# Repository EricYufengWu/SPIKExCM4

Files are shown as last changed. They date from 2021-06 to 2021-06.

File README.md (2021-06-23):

## Raspberry Pi CM4 Carrier Board for LEGO SPIKE Prime

This is the final project for my Microcontrollers Programming Class. My professor gave us an open prompt which is "create something that is useful". With my previous experience and interests in designing LEGO Robotics expansion hardware, I developed a Raspberry Pi CM4 Carrier board specifically for the LEGO SPIKE Prime educational system. In short, this is a slim, self-contained add-on to the SPIKE Prime hub. It gives the educational platform a huge boost in computational power and peripheral connectivity, making it capable of running tasks such as image processing, machine learning, ROS, and more.

**Note: As of June 23rd, 2021, the camera ports unfortunately do not work on the current version (In short, I made a dumb mistake of using a different footprint for the camera connectors, which has all the pins backwards). Connecting a camera may result in the flex cable heating up or possibly some permanent damage to the CM4 board. If I ever got the chance to make another design iteration, this will be the first thing I will tackle. :(**

Youtube: https://youtu.be/AbPgGo25kjA

GrabCAD: https://grabcad.com/library/raspberry-pi-cm4-carrier-board-for-lego-spike-prime-1

For more information about this project, please checkout https://www.yufengwu.com/work/class-projects/cm4-carrier-board

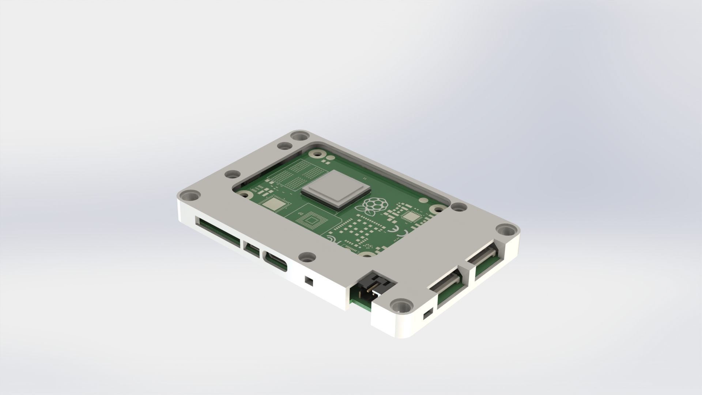
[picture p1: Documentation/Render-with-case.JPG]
Rendering

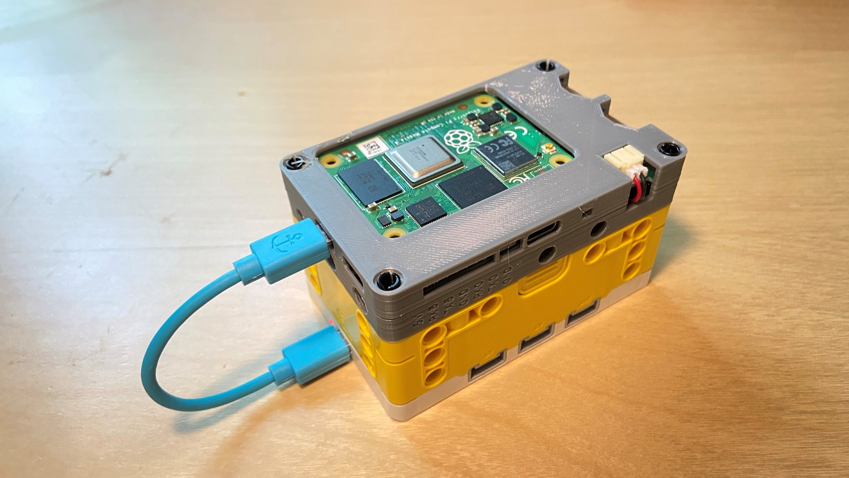
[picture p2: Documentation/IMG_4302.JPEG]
Finished


## Hardware Components
To make this backpack yourself, you'll need the following hardware components:
* The carrier board PCB itself. I got the full assembly service from PCBWay, but you are welcome to find your own PCB manufacturer.
* A [Raspberry Pi Compute Module 4](https://www.raspberrypi.org/products/compute-module-4/?variant=raspberry-pi-cm4001000) **with onboard EMMC and WiFi module**. 
* Some right-angle pin headers. [Amazon Link](https://www.amazon.com/Uxcell-a14032500ux0426-Right-Header-Spacing/dp/B010ESD338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)
* A 3.7V Lithium Polymer (LiPoly) battery with JST-PH connector in the correct polarity. It has to be both slim enough to fit inside the housing and powerful enough to handle around 1.5A nominal and 3A burst current. [Digikey Link](https://www.digikey.com/en/products/detail/jauch-quartz/LP605060JU-PCM-WIRES-70MM/9560993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)
* A short microB male to microB male USB cable. [Digikey Link](https://www.digikey.com/en/products/detail/CAB0701/1778-1018-ND/6928231?itemSeq=364421679)
* A standard hobbyist 3D printer with PLA filament (Prusa MK3S, Prusa MINI, Ender3, etc.).

## Getting Started with the Carrier Board
1. Install the compute module onto the carrier board. Make sure to get one with EMMC memory (you probably want one with WiFi as well)
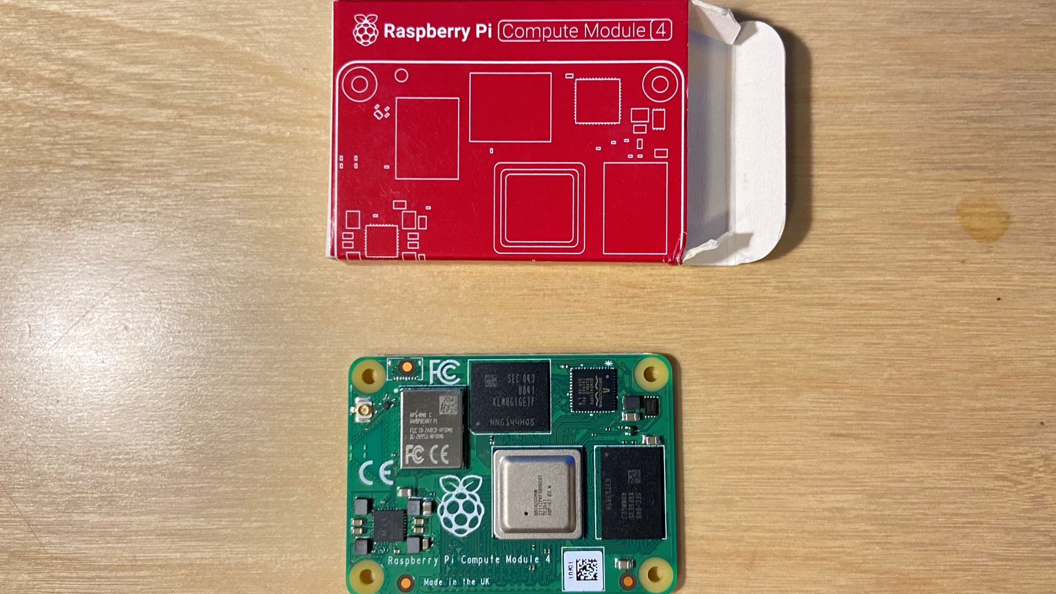
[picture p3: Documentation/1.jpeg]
CM4


1. Close the jumper (see pic) to disable EMMC boot. 
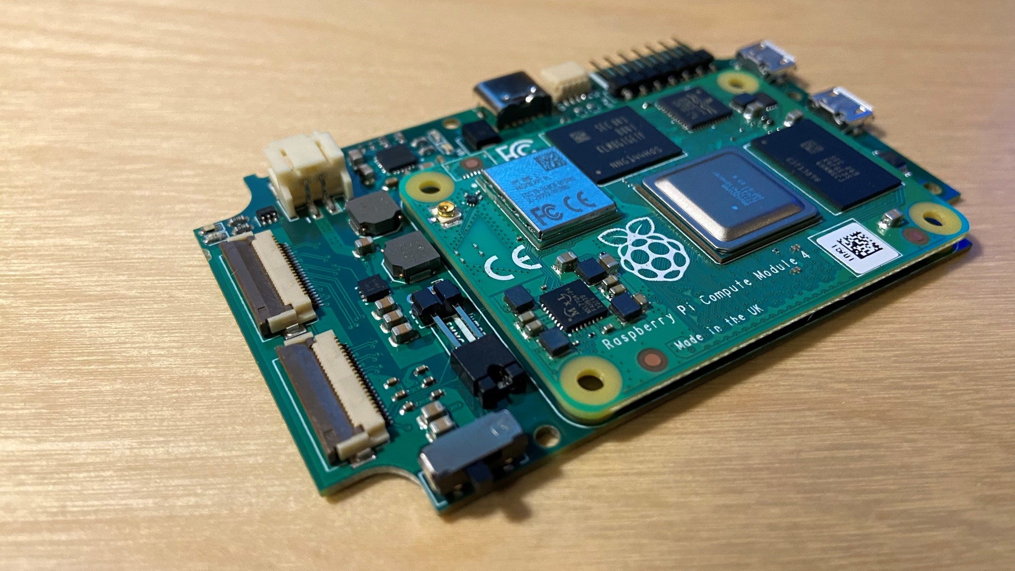
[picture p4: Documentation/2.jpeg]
Jumper Open

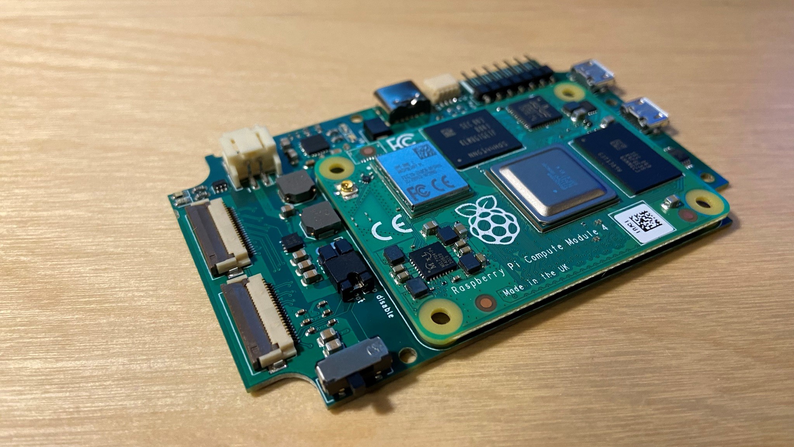
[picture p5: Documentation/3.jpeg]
Jumper Closed


1. Connect a microUSB data cable from the OTG port (the one closer to the corner) to your laptop.
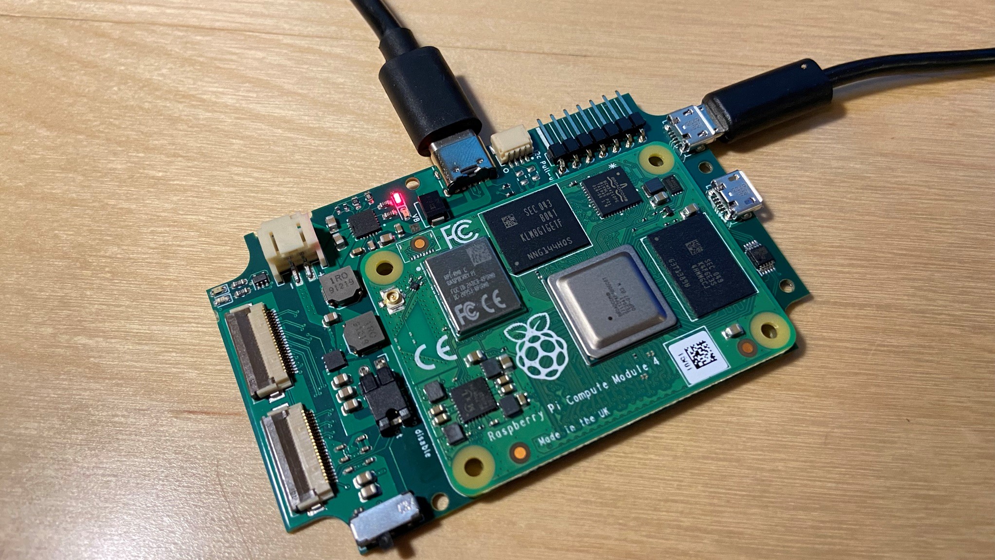
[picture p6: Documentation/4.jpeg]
OTG


1. Follow [this link](https://www.raspberrypi.org/documentation/hardware/computemodule/cm-emmc-flashing.md) to flash the compute module's EMMC. The spscific steps depend on your computer's operating system (see the link for details). After this, you should have an operating system of your choice installed on the compute module. 

1. To minimize its size, this board is designed to have your Pi communicate with your computer via a serial console cable. You may now follow [this link](https://learn.adafruit.com/adafruits-raspberry-pi-lesson-5-using-a-console-cable/overview) to set up the communication. As for the "Connecting the Lead" section, refer to the following picture for wiring. Specifically, you'll want the following line of text be added to the last line of config.txt, which you may found in your Pi as a mass storage device right after writing the OS onto your compute module.
    ```
    enable_uart=1
    ```
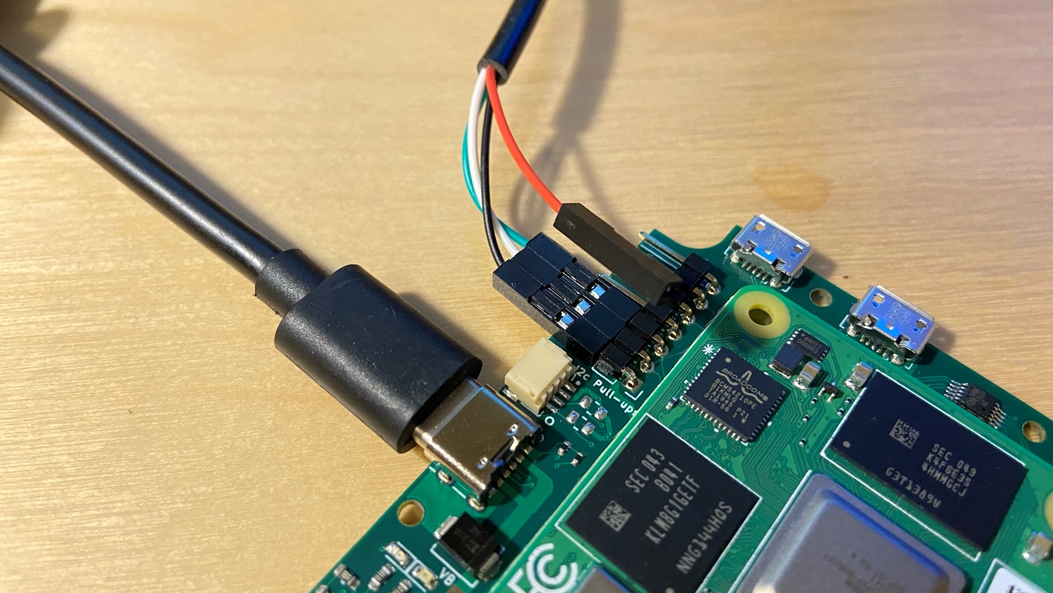
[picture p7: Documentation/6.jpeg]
Serial Console


1. For thir carrier board specifically, you also might want to add the following to config.txt, since the GPIO pins for UART5 were also made available in case you want to use the console cable and UART at the same time.
    ```
    dtoverlay=uart5
    ```

1. If the TTL cable connection is successful, you may continue to set up other hardware, such as WiFi and USB, in order to release the full potential of your compute module. You may use a short microB male to microB male USB cable to connect your carriar board to a LEGO SPIKE Prime. To enable USB, add the following line to config.txt:
    ```
    dtoverlay=dwc2,dr_mode=host
    ```

1. Happy hacking!

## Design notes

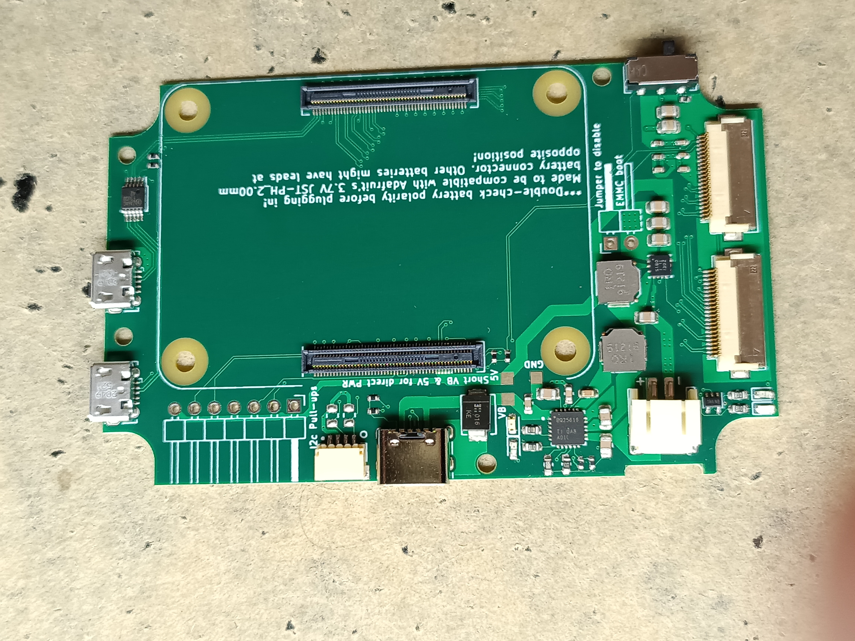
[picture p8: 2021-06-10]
Documentation/Finished_front.jpg

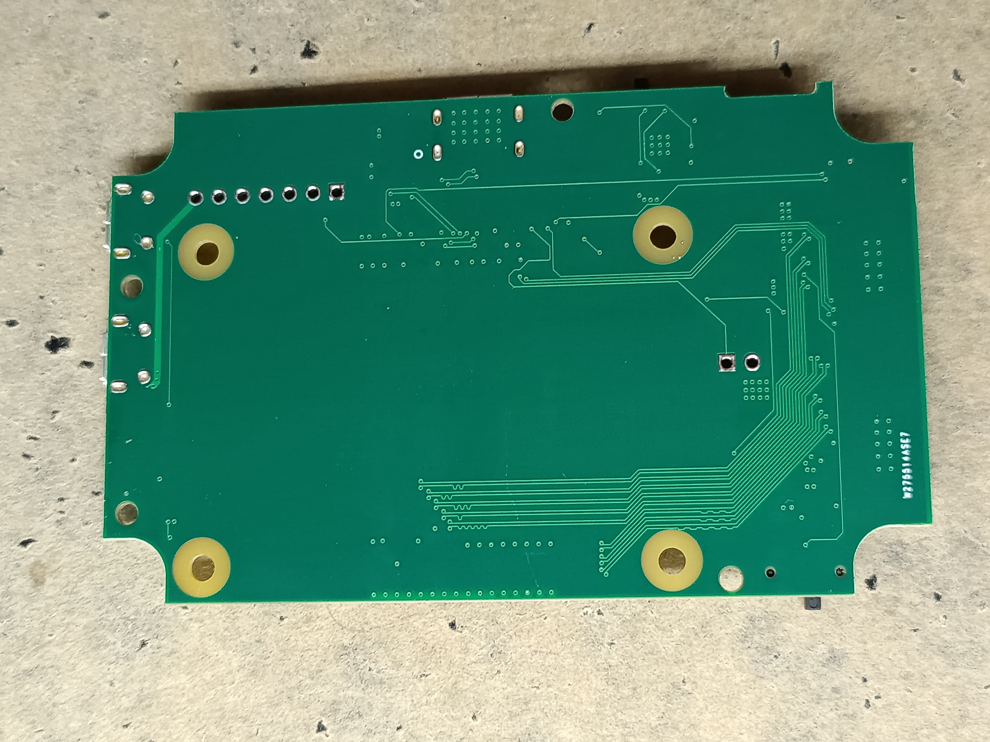
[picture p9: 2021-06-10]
Documentation/Finished_back.jpg

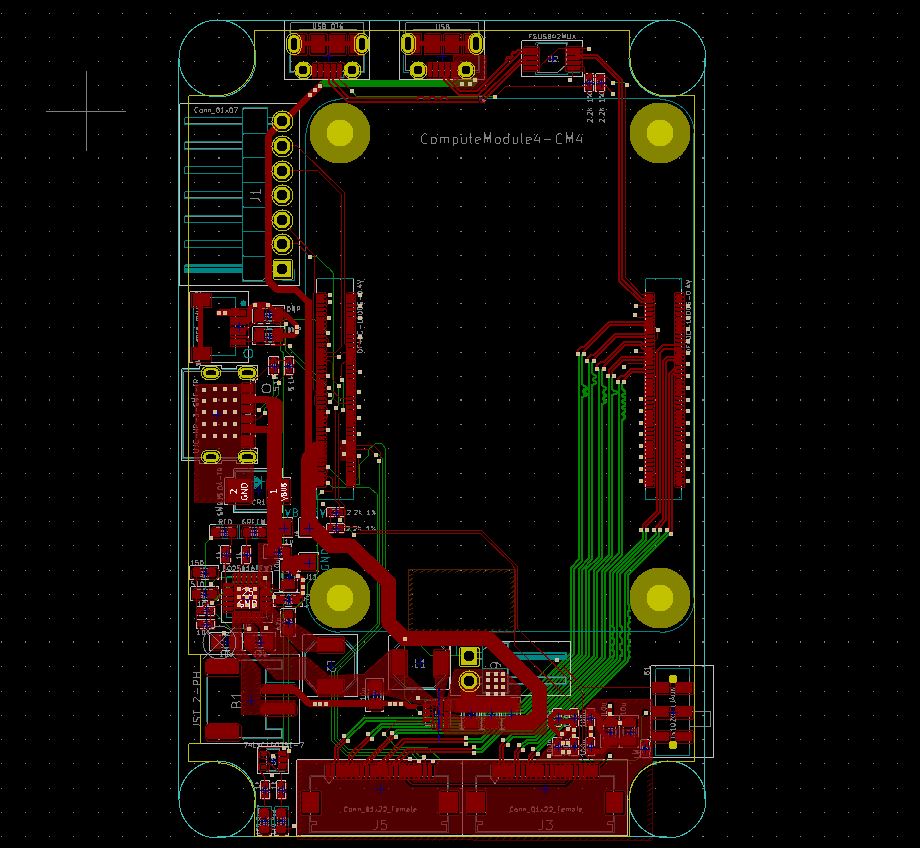
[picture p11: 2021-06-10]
Documentation/layout.JPG

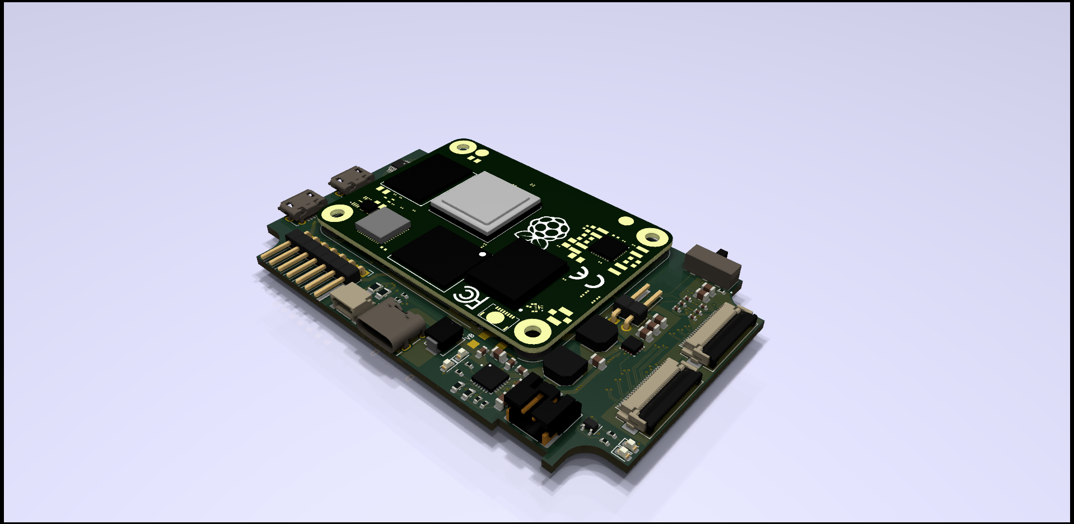
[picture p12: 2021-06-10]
Documentation/rpi-cm4-carrier-v0-render.png

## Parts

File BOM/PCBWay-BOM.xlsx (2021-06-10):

 |  |  | xxxx xxxx xxxxx xxPCS BOM (Sample Bill of Materials)
Item # | *Designator | *Qty | Manufacturer | *Mfg Part # | Description / Value | *Package/Footprint | Type | Your Instructions / Notes
1 | B1 | 1 | JST Sales America Inc. | S2B-PH-SM4-TB(LF)(SN) | Connector Header Surface Mount, Right Angle 2 position 0.079" (2.00mm) | 2.00mm pitch | SMD | https://www.digikey.com/en/products/detail/jst-sales-america-inc/S2B-PH-SM4-TB-LF-SN/926655
2 | C1,C2,C9,C10,C12,C13,C14,C17,C18 | 9 | Samsung Electro-Mechanics | CL21A106KPFNNWE | 10uF ±10% 10V Ceramic Capacitor X5R 0805 (2012 Metric) | 0805 | SMD | https://www.digikey.com/en/products/detail/samsung-electro-mechanics/CL21A106KPFNNWE/3888555
3 | C3,C4,C5,C6,C7,C8 | 6 | Samsung Electro-Mechanics | CL05B104KP5NNNC | 0.1uF ±10% 10V Ceramic Capacitor X7R 0402 (1005 Metric) | 0402 | SMD | https://www.digikey.com/en/products/detail/samsung-electro-mechanics/CL05B104KP5NNNC/3886660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
4 | C11 | 1 | Samsung Electro-Mechanics | CL10B105KP8NNNC | 1uF ±10% 10V Ceramic Capacitor X7R 0603 (1608 Metric) | 0603 | SMD | https://www.digikey.com/en/products/detail/samsung-electro-mechanics/CL10B105KP8NNNC/3887604
5 | C15 | 1 | Vishay Vitramon | VJ0603Y473JXQPW1BC | 0.047uF ±5% 10V Ceramic Capacitor X7R 0603 (1608 Metric) | 0603 | SMD | https://www.digikey.com/en/products/detail/vishay-vitramon/VJ0603Y473JXQPW1BC/8306338
6 | C16 | 1 | Samsung Electro-Mechanics | CL10A475KP8NNNC | 4.7uF ±10% 10V Ceramic Capacitor X5R 0603 (1608 Metric) | 0603 | SMD | https://www.digikey.com/en/products/detail/samsung-electro-mechanics/CL10A475KP8NNNC/3886702
7 | CR1 | 1 | Diodes Incorporated | SMBJ5.0A-13-F | TVS DIODE 5V 9.2V SMB | DO-214AA, SMB | SMD | https://www.digikey.com/en/products/detail/diodes-incorporated/SMBJ5-0A-13-F/725039
8 | D1,D3 | 2 | OSRAM Opto Semiconductors Inc. | LG Q396-PS-35 | Green 573nm LED Indication - Discrete 2V 0603 (1608 Metric) | 0603 | SMD | https://www.digikey.com/en/products/detail/osram-opto-semiconductors-inc/LG-Q396-PS-35/5249855
9 | D2,D4 | 2 | OSRAM Opto Semiconductors Inc. | LED RED DIFFUSED 0603 SMD | Red 630nm LED Indication - Discrete 1.8V 0603 (1608 Metric) | 0603 | SMD | https://www.digikey.com/en/products/detail/osram-opto-semiconductors-inc/LS-L29K-G1J2-1-Z/1227979
11 | J2 | 1 | JST Sales America Inc. | SM04B-SRSS-TB(LF)(SN) | Connector Header Surface Mount, Right Angle 4 position 0.039" (1.00mm) | 1.00mm pitch | SMD | https://www.digikey.com/en/products/detail/hirose-electric-co-ltd/FH12-22S-0-5SH-55/1110321
12 | J3,J5 | 2 | Hirose Electric Co Ltd | FH12-22S-0.5SH(55) | 22 Position FFC, FPC Connector Contacts, Bottom 0.020" (0.50mm) Surface Mount, Right Angle | 0.50mm pitch | SMD | https://www.digikey.com/en/products/detail/jst-sales-america-inc/SM04B-SRSS-TB-LF-SN/926710
13 | J6,J7 | 2 | Molex | 1050170001 | USB - micro B USB 2.0 Receptacle Connector 5 Position Surface Mount, Right Angle; Through Hole | https://www.molex.com/pdm_docs/sd/1050170001_sd.pdf | SMD | https://www.digikey.com/en/products/detail/molex/1050170001/2350832
14 | J8 | 1 | CUI Devices | UJC-HP-3-SMT-TR | USB-C (USB TYPE-C) - Power Only - Receptacle Connector 24 (6+18 Dummy) Position Surface Mount, Right Angle; Through Hole | https://www.cuidevices.com/product/resource/ujc-hp-3-smt-tr.pdf | SMD | https://www.digikey.com/en/products/detail/cui-devices/UJC-HP-3-SMT-TR/12173295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
15 | L1,L2 | 2 | TDK Corporation | SPM5020T-1R0M-LR | Shielded Wirewound Inductor 17.2mOhm Max Nonstandard | Nonstandard | SMD | https://www.digikey.com/en/products/detail/tdk-corporation/SPM5020T-1R0M-LR/5962359
16 | Module1 (2 pieces) | 2 | Hirose Electric Co Ltd | DF40C-100DS-0.4V(51) | 100 Position Connector Receptacle, Center Strip Contacts Surface Mount Gold | Raspberry Pi CM4 | SMD | https://www.digikey.com/en/products/detail/hirose-electric-co-ltd/DF40C-100DS-0-4V-51/1969476
17 | R1,R4,R14,R15 | 4 | Samsung Electro-Mechanics | RC1608F102CS | RES SMD 1K OHM 1% 1/10W 0603 | 0603 | SMD | https://www.digikey.com/en/products/detail/samsung-electro-mechanics/RC1608F102CS/3903492
18 | R2, R3 | 2 | DO NOT PLACE | DO NOT PLACE | DO NOT PLACE | 0805 | SMD | DO NOT PLACE
19 | R5,R6,R7,R8 | 4 | Samsung Electro-Mechanics | RC1005F222CS | RES SMD 2.2K OHM 1% 1/16W 0402 | 0402 | SMD | https://www.digikey.com/en/products/detail/samsung-electro-mechanics/RC1005F222CS/3964353
20 | R9,R11 | 2 | Samsung Electro-Mechanics | RC1005F512CS | RES SMD 5.1K OHM 1% 1/16W 0402 | 0402 | SMD | https://www.digikey.com/en/products/detail/samsung-electro-mechanics/RC1005F512CS/3964392
21 | R10 | 1 | Yageo | RC0402FR-071ML | RES SMD 1M OHM 1% 1/16W 0402 | 0402 | SMD | https://www.digikey.com/en/products/detail/yageo/RC0402FR-071ML/726515
22 | R12 | 1 | Yageo | RC0603FR-07150RL | RES SMD 150 OHM 1% 1/10W 0603 | 0603 | SMD | https://www.digikey.com/en/products/detail/yageo/RC0603FR-07150RL/726958
23 | R13 | 1 | Yageo | RC0603FR-07510RL | RES SMD 510 OHM 1% 1/10W 0603 | 0603 | SMD | https://www.digikey.com/en/products/detail/yageo/RC0603FR-07510RL/727285
24 | R16,R17 | 2 | Samsung Electro-Mechanics | RC1005F103CS | RES SMD 10K OHM 1% 1/16W 0402 | 0402 | SMD | https://www.digikey.com/en/products/detail/samsung-electro-mechanics/RC1005F103CS/3903439
25 | S1 | 1 | C&K | JS102011JAQN | SWITCH SLIDE SPDT 300MA 6V | Nonstandard | SMD | https://www.digikey.com/en/products/detail/c-k/JS102011JAQN/6137627?s=N4IgTCBcDaIFYGcCMAGMKlLgQwI4DsQBdAXyA
26 | U1 | 1 | Diodes Incorporated | 74LVC1G07SE-7 | IC BUF NON-INVERT 5.5V SOT353 | SOT353 | SMD | https://www.digikey.com/en/products/detail/diodes-incorporated/74LVC1G07SE-7/2356534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
27 | U2 | 1 | ON Semiconductor | FSUSB42MUX | IC USB SWITCH DPDT 10MSOP | 10MSOP | SMD | https://www.digikey.com/en/products/detail/on-semiconductor/FSUSB42MUX/2036916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
28 | U4 | 1 | Texas Instruments | TPS61235PRWLR | Boost Switching Regulator IC Positive Fixed 5.1V 1 Output 6.5A (Switch) 9-VFQFN | 9VQFN | SMD | https://www.digikey.com/en/products/detail/texas-instruments/TPS61235PRWLR/6140193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
29 | U5 | 1 | Texas Instruments | BQ25616RTWT | IC BATT CHG LI-ION 1CELL 24WQFN | 24WQFN | SMD | https://www.digikey.com/en/products/detail/texas-instruments/BQ25616RTWT/11615843
Need a quick and accurante quote? Need an efficient production? Please read SMT Ordering Necessary Files & Info in 1 minute. Thank you very much! (https://www.pcbway.com/smt_ordering_guide.html)
Click for Instructions on How to Create a BOM (https://www.pcbway.com/blog/PCB_Assembly/How_to_Build_a_BOM__Bill_Of_Materials_.html)

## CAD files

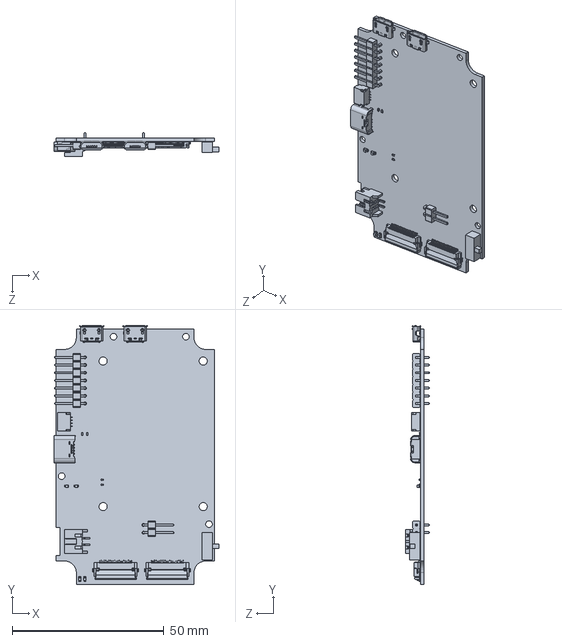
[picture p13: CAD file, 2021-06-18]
CAD/rpi-cm4-carrier-simplified-prt-rev3.SLDPRT
54.2 x 85.4 x 7.80 mm

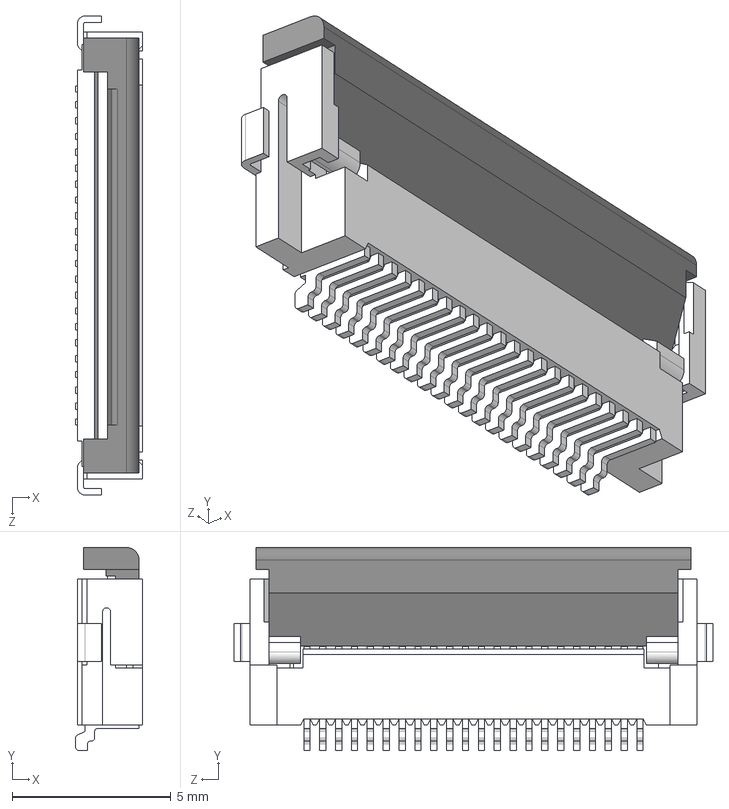
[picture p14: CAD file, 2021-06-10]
CAD/STEP/FH12-22S-0.5SH.STEP
2.10 x 6.40 x 15.1 mm

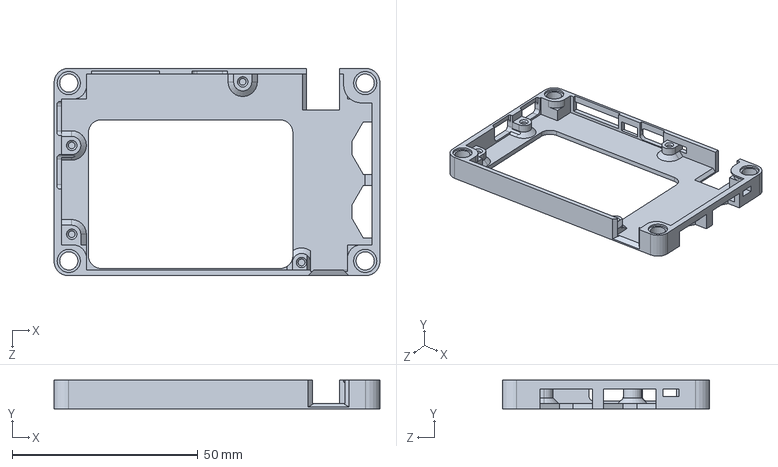
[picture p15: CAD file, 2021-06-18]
CAD/rpi-cm4-carrier-attachment.SLDPRT
87.7 x 7.75 x 55.8 mm

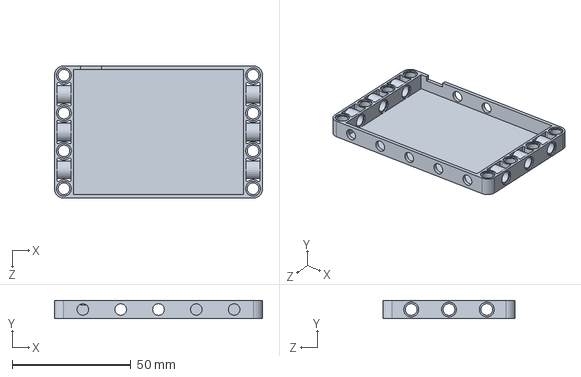
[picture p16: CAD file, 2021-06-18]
CAD/rpi-cm4-carrier-attachment-battery.SLDPRT
87.7 x 7.75 x 55.8 mm

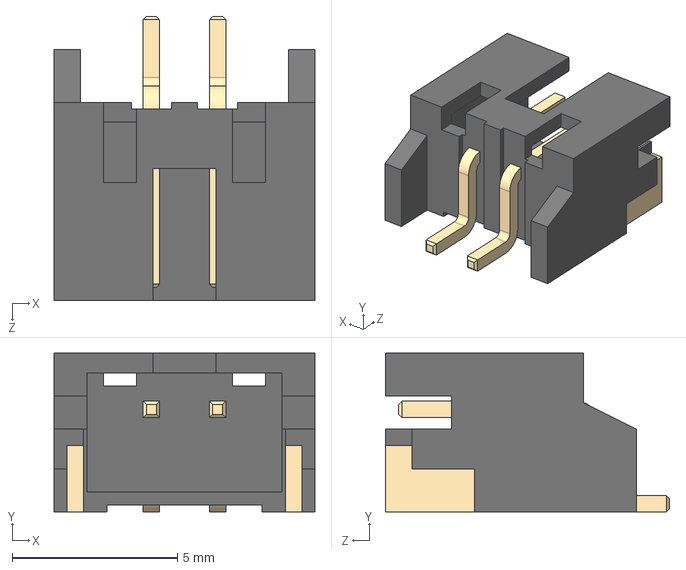
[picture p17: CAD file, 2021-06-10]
CAD/STEP/JST-PH-SM4.STEP
7.90 x 4.80 x 8.60 mm

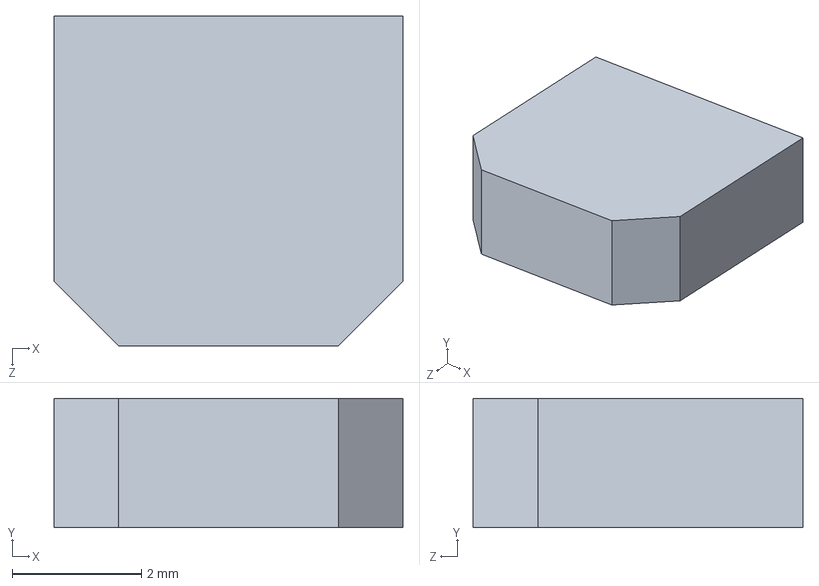
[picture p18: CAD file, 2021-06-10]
CAD/STEP/SPM5020T-1R0M.STEP
5.40 x 2.00 x 5.10 mm

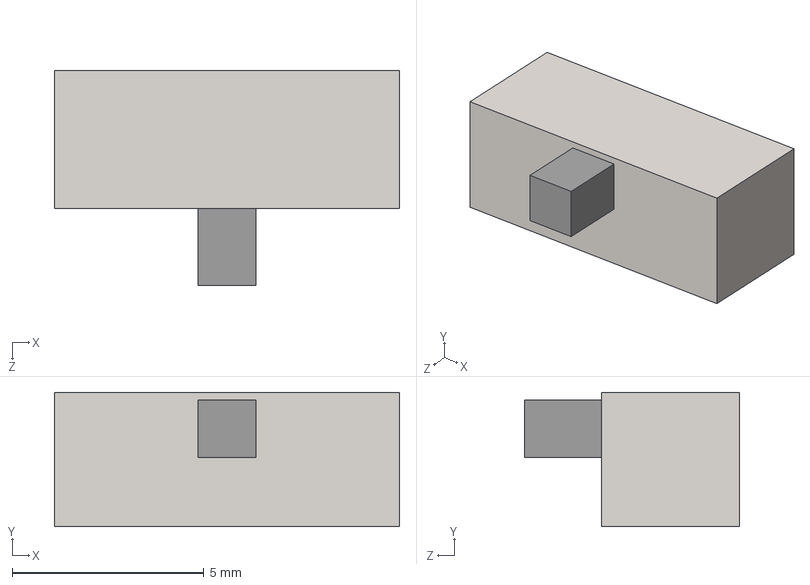
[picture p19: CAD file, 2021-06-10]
CAD/STEP/SPDT-SW-JS102011JAQN.STEP
9.00 x 3.50 x 5.60 mm

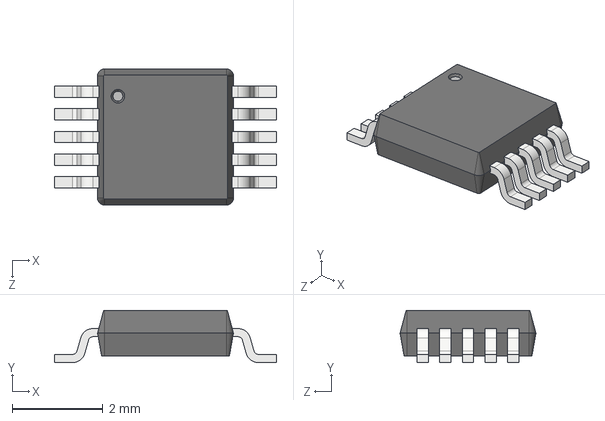
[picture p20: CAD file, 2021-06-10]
CAD/STEP/FSUSB42MUX.STEP
4.90 x 1.15 x 3.00 mm

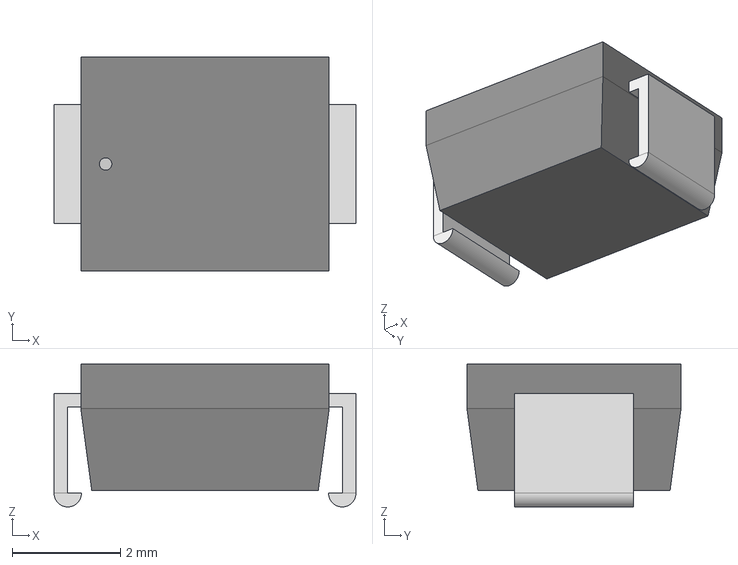
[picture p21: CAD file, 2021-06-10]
CAD/STEP/SMB_STM.step
5.59 x 3.96 x 2.64 mm

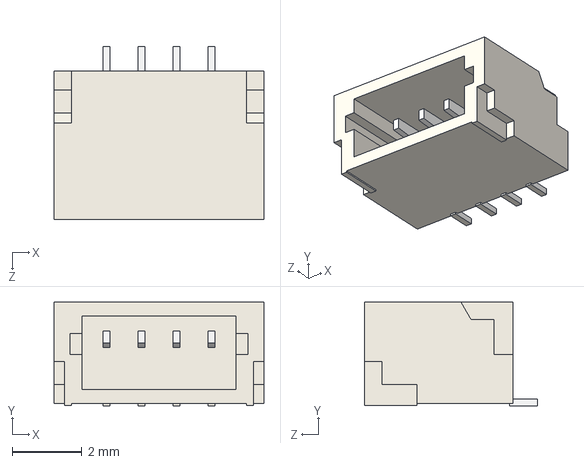
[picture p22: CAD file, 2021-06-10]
CAD/STEP/JST-SH-STEMMA.STEP
6.00 x 2.96 x 4.95 mm

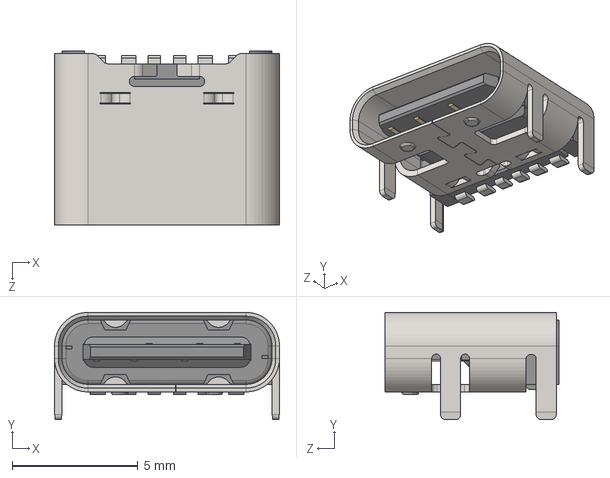
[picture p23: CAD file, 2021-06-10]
CAD/STEP/UJC-HP-3-SMT-TR.STEP
8.94 x 4.26 x 6.90 mm

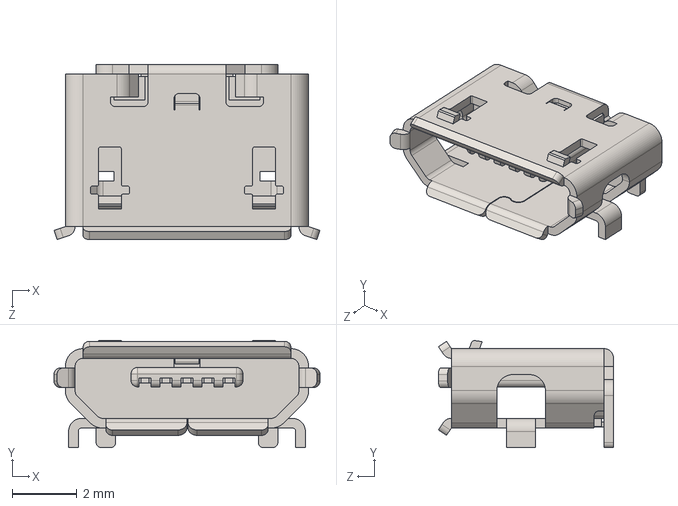
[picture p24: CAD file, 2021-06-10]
CAD/STEP/molex-105017-0001.stp
8.20 x 3.30 x 5.40 mm

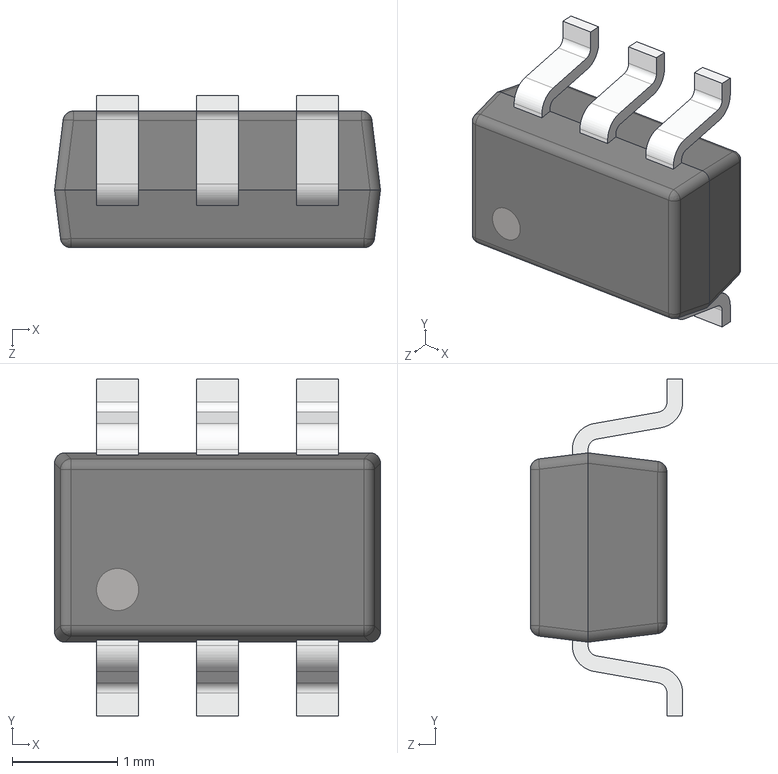
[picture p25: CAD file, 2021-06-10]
CAD/STEP/‎74LVC1G07SE-7.STEP
3.10 x 3.20 x 1.45 mm

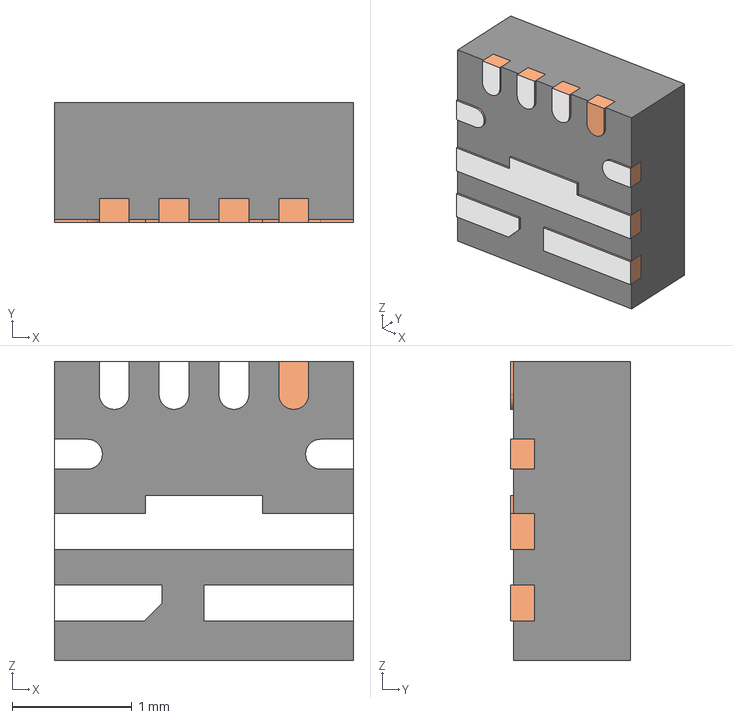
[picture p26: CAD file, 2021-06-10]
CAD/STEP/TPS61235.stp
2.50 x 1.00 x 2.50 mm
FRAME-RWL0009A
BODY-QFN

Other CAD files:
CAD/STEP/S2B-PH-SM4-TB.stp
CAD/STEP/camera-FH12-22S-0.5SH.STEP
CAD/STEP/BQ25616RTWT.STEP

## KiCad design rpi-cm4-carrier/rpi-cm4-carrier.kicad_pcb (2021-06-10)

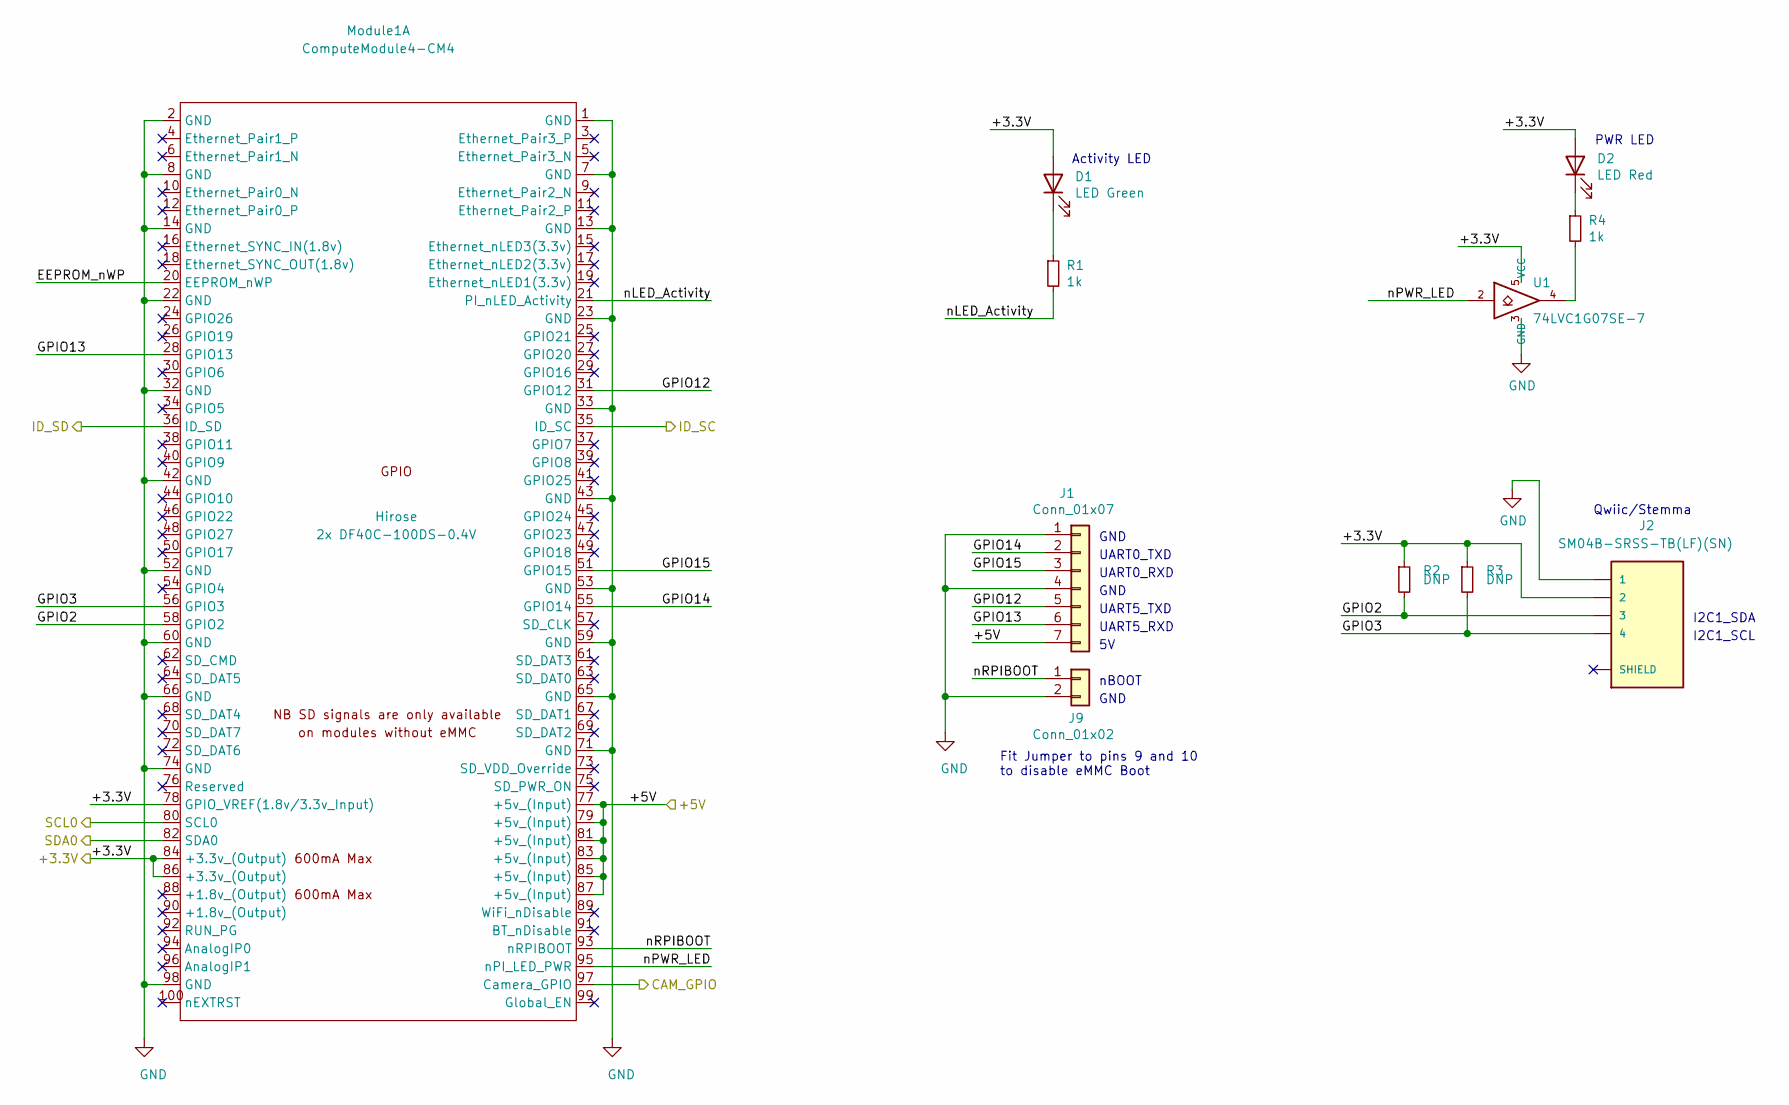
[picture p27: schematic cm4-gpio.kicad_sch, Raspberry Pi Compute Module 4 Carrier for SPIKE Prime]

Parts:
D1: LED Green; LED_0603_1608Metric; Part Description Green 572nm LED Indication - Discrete 2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; Digi-Key_PN 160-1478-1-ND
D2: LED Red; LED_0603_1608Metric; Part Description Red 620nm LED Indication - Discrete 2.2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; Digi-Key_PN 160-1479-1-ND
J1: Conn_01x07; PinHeader_1x07_P2.54mm_Horizontal
J2: SM04B-SRSS-TB(LF)(SN); JST_SM04B-SRSS-TB(LF)(SN); MPN SM04B-SRSS-TB(LF)(SN); Digi-Key_PN 455-1804-1-ND
J9: Conn_01x02; PinHeader_1x02_P2.54mm_Horizontal
Module1: ComputeModule4-CM4; Raspberry-Pi-4-Compute-Module; MPN 2x DF40C-100DS-0.4V; Digi-Key_PN 2x H11615CT-ND
R1, R4: 1k; R_0603_1608Metric; MPN RC0603FR-071KL; Digi-Key_PN 311-1.00KHRCT-ND
R2, R3: DNP; R_0805_2012Metric
U1: 74LVC1G07SE-7; SOT-353_SC-70-5; Part Description Buffer, Non-Inverting 1 Element 1 Bit p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; Digi-Key_PN 74LVC1G07SE-7DICT-ND

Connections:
/+3.3v: D1.2 (A), D2.2 (A), J2.2, Module1.78 (GPIO_VREF(1.8v/3.3v_Input)), Module1.84 (+3.3v_(Output)), Module1.86 (+3.3v_(Output)), R2.1, R3.1, U1.5 (VCC); also elsewhere on the board
/+5v: J1.7, Module1.77 (+5v_(Input)), Module1.79 (+5v_(Input)), Module1.81 (+5v_(Input)), Module1.83 (+5v_(Input)), Module1.85 (+5v_(Input)), Module1.87 (+5v_(Input)); also elsewhere on the board
/CM4 GPIO/EEPROM_nWP: Module1.20 (EEPROM_nWP)
/CM4 GPIO/GPIO2: J2.3, Module1.58 (GPIO2), R2.2
/CM4 GPIO/GPIO3: J2.4, Module1.56 (GPIO3), R3.2
/CM4 GPIO/GPIO12: J1.5, Module1.31 (GPIO12)
/CM4 GPIO/GPIO13: J1.6, Module1.28 (GPIO13)
/CM4 GPIO/GPIO14: J1.2, Module1.55 (GPIO14)
/CM4 GPIO/GPIO15: J1.3, Module1.51 (GPIO15)
/CM4 GPIO/nLED_Activity: Module1.21 (PI_nLED_Activity), R1.2
/CM4 GPIO/nPWR_LED: Module1.95 (nPI_LED_PWR), U1.2
/CM4 GPIO/nRPIBOOT: J9.1, Module1.93 (nRPIBOOT)
/CM4 High Speed/CAM_GPIO: Module1.97 (Camera_GPIO); also elsewhere on the board
/CM4 High Speed/ID_SC: Module1.35 (ID_SC); also elsewhere on the board
/CM4 High Speed/ID_SD: Module1.36 (ID_SD); also elsewhere on the board
/CM4 High Speed/SCL0: Module1.80 (SCL0); also elsewhere on the board
/CM4 High Speed/SDA0: Module1.82 (SDA0); also elsewhere on the board
GND: J1.1, J1.4, J2.1, J9.2, Module1.1 (GND), Module1.2 (GND), Module1.7 (GND), Module1.8 (GND), Module1.13 (GND), Module1.14 (GND), Module1.22 (GND), Module1.23 (GND), Module1.32 (GND), Module1.33 (GND), Module1.42 (GND), Module1.43 (GND), Module1.52 (GND), Module1.53 (GND), Module1.59 (GND), Module1.60 (GND), Module1.65 (GND), Module1.66 (GND), Module1.71 (GND), Module1.74 (GND), Module1.98 (GND), U1.3 (GND); also elsewhere on the board
unnamed: D1.1 (K), R1.1
unnamed: D2.1 (K), R4.1
unnamed: R4.2, U1.4

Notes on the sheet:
Fit Jumper to pins 9 and 10 to disable eMMC Boot
Activity LED
GND
UART0_TXD
UART0_RXD
UART5_TXD
UART5_RXD
nBOOT
PWR LED
Qwiic/Stemma
I2C1_SDA
I2C1_SCL

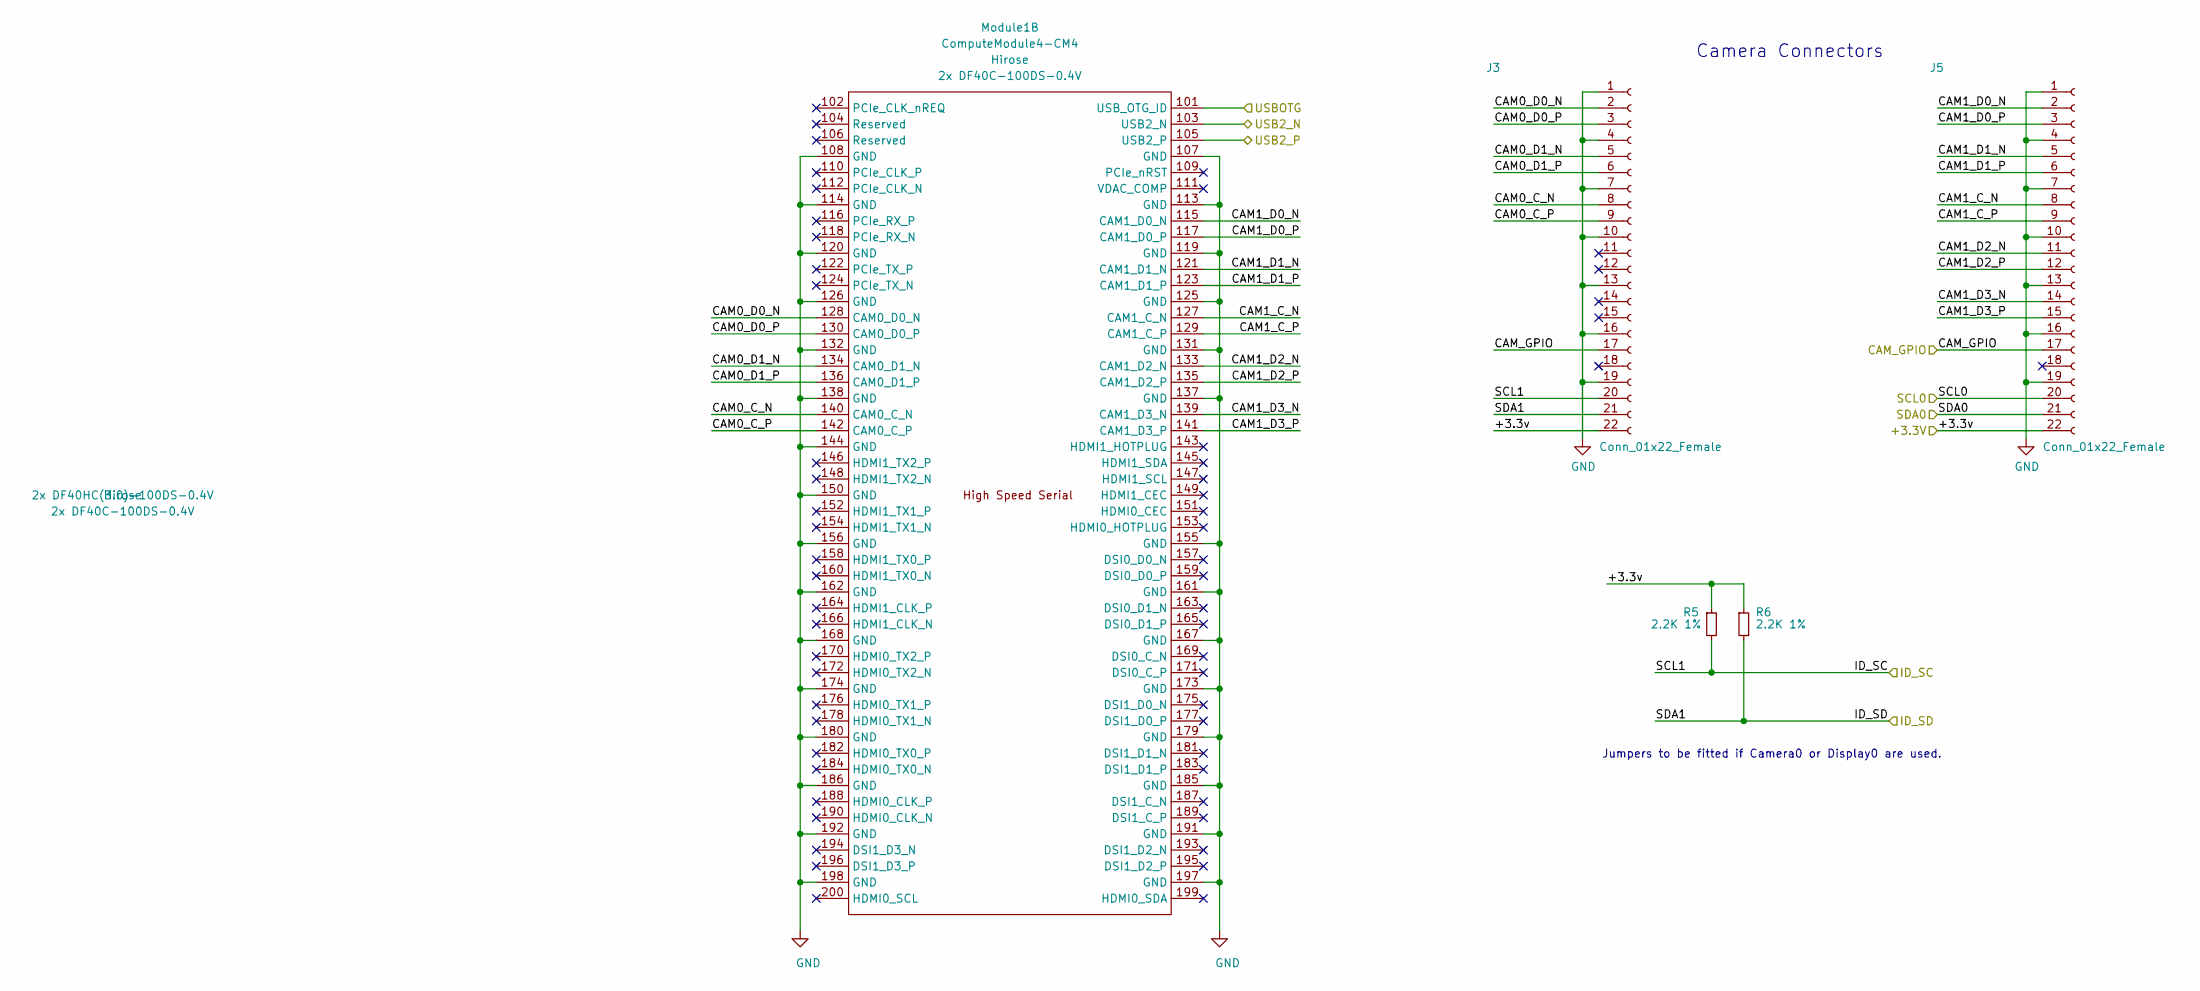
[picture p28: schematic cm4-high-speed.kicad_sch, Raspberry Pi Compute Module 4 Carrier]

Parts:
J3, J5: Conn_01x22_Female; Hirose_FH12-22S-0.5SH_1x22-1MP_P0.50mm_Horizontal; Part Description 22 Position FFC, FPC Connector Contacts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
Module1: ComputeModule4-CM4; Raspberry-Pi-4-Compute-Module; MPN 2x DF40C-100DS-0.4V; Digi-Key_PN 2x H11615CT-ND
R5, R6: 2.2K 1%; R_0402_1005Metric; Part Description Resistor 2.2K M1005 1% 63mW

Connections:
/+3.3v: J3.22, J5.22, R5.1, R6.1; also elsewhere on the board
/CM4 High Speed/CAM0_C_N: J3.8, Module1.140 (CAM0_C_N)
/CM4 High Speed/CAM0_C_P: J3.9, Module1.142 (CAM0_C_P)
/CM4 High Speed/CAM0_D0_N: J3.2, Module1.128 (CAM0_D0_N)
/CM4 High Speed/CAM0_D0_P: J3.3, Module1.130 (CAM0_D0_P)
/CM4 High Speed/CAM0_D1_N: J3.5, Module1.134 (CAM0_D1_N)
/CM4 High Speed/CAM0_D1_P: J3.6, Module1.136 (CAM0_D1_P)
/CM4 High Speed/CAM1_C_N: J5.8, Module1.127 (CAM1_C_N)
/CM4 High Speed/CAM1_C_P: J5.9, Module1.129 (CAM1_C_P)
/CM4 High Speed/CAM1_D0_N: J5.2, Module1.115 (CAM1_D0_N)
/CM4 High Speed/CAM1_D0_P: J5.3, Module1.117 (CAM1_D0_P)
/CM4 High Speed/CAM1_D1_N: J5.5, Module1.121 (CAM1_D1_N)
/CM4 High Speed/CAM1_D1_P: J5.6, Module1.123 (CAM1_D1_P)
/CM4 High Speed/CAM1_D2_N: J5.11, Module1.133 (CAM1_D2_N)
/CM4 High Speed/CAM1_D2_P: J5.12, Module1.135 (CAM1_D2_P)
/CM4 High Speed/CAM1_D3_N: J5.14, Module1.139 (CAM1_D3_N)
/CM4 High Speed/CAM1_D3_P: J5.15, Module1.141 (CAM1_D3_P)
/CM4 High Speed/CAM_GPIO: J3.17, J5.17; also elsewhere on the board
/CM4 High Speed/ID_SC: J3.20, R5.2; also elsewhere on the board
/CM4 High Speed/ID_SD: J3.21, R6.2; also elsewhere on the board
/CM4 High Speed/SCL0: J5.20; also elsewhere on the board
/CM4 High Speed/SDA0: J5.21; also elsewhere on the board
/CM4 High Speed/USB2_N: Module1.103 (USB2_N); also elsewhere on the board
/CM4 High Speed/USB2_P: Module1.105 (USB2_P); also elsewhere on the board
/CM4 High Speed/USBOTG: Module1.101 (USB_OTG_ID); also elsewhere on the board
GND: J3.1, J3.4, J3.7, J3.10, J3.13, J3.16, J3.19, J5.1, J5.4, J5.7, J5.10, J5.13, J5.16, J5.19, Module1.107 (GND), Module1.108 (GND), Module1.113 (GND), Module1.114 (GND), Module1.119 (GND), Module1.120 (GND), Module1.125 (GND), Module1.126 (GND), Module1.131 (GND), Module1.132 (GND), Module1.137 (GND), Module1.138 (GND), Module1.144 (GND), Module1.150 (GND), Module1.155 (GND), Module1.156 (GND), Module1.161 (GND), Module1.162 (GND), Module1.167 (GND), Module1.168 (GND), Module1.173 (GND), Module1.174 (GND), Module1.179 (GND), Module1.180 (GND), Module1.185 (GND), Module1.186 (GND), Module1.191 (GND), Module1.192 (GND), Module1.197 (GND), Module1.198 (GND); also elsewhere on the board

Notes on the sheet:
Camera Connectors
Jumpers to be fitted if Camera0 or Display0 are used.

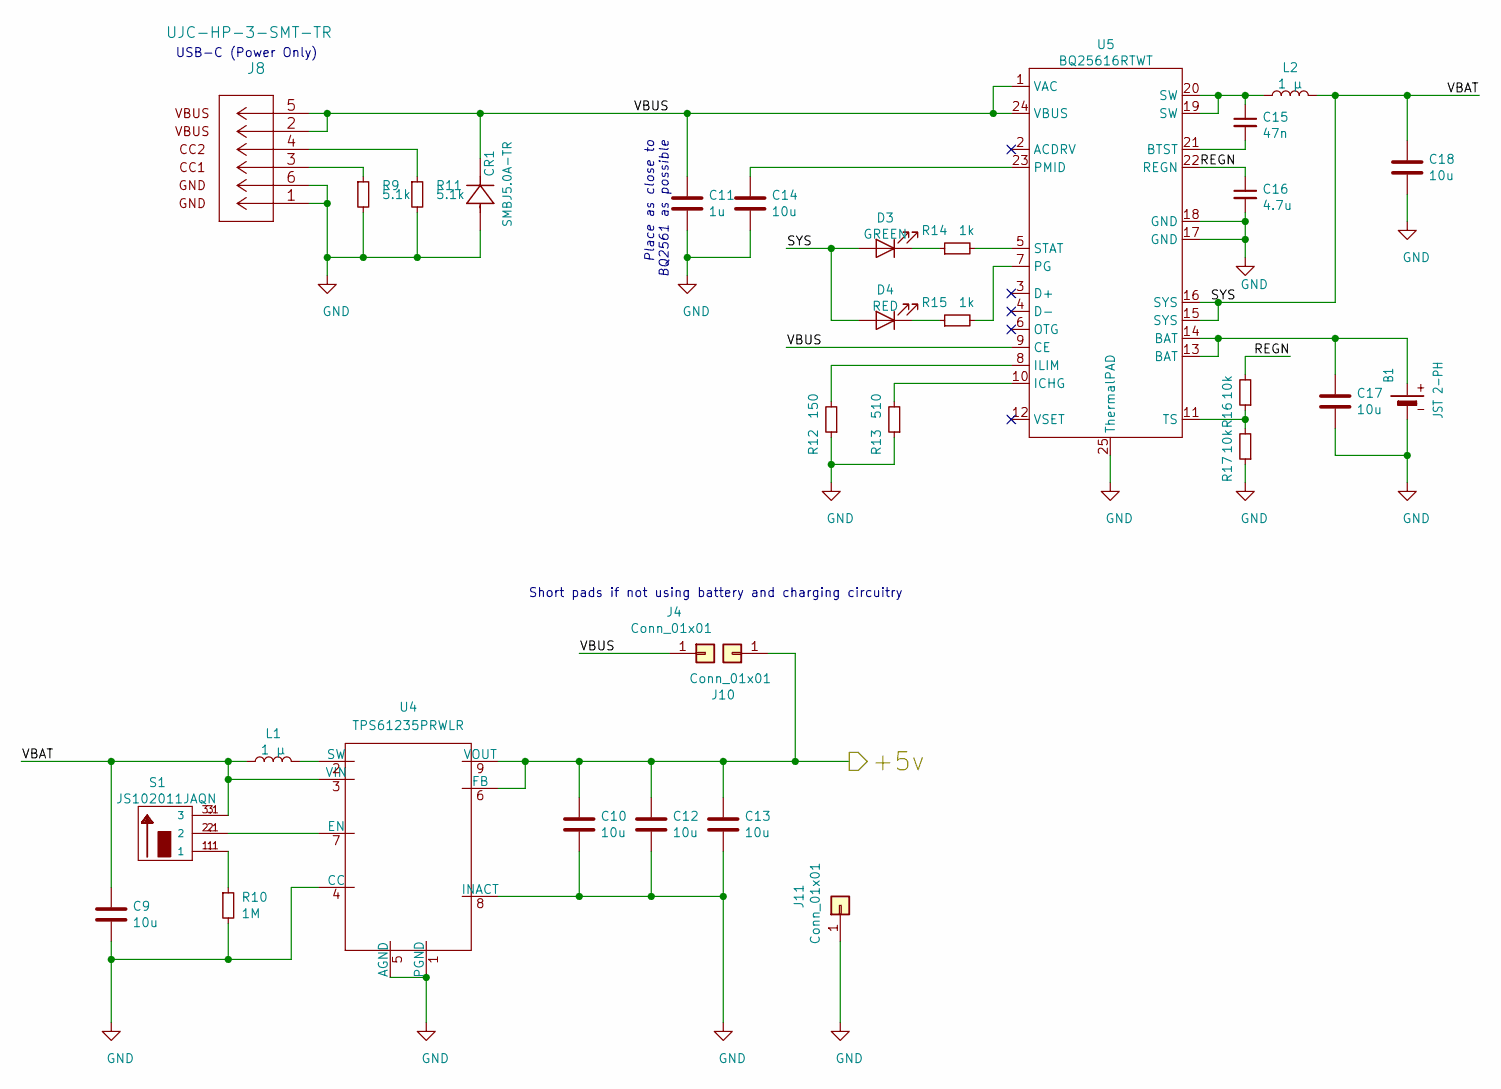
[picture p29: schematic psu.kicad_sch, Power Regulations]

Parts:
B1: JST 2-PH; JST_PH_S2B-PH-SM4-TB_1x02-1MP_P2.00mm_Horizontal
C9, C10, C12, C13, C14, C17, C18: 10u; C_0805_2012Metric; Part Description 10uF 10% 10V Ceramic Capacitor X7R 0805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
C11: 1u; C_0603_1608Metric; Part Description 10uF 10% 10V Ceramic Capacitor X7R 0805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
C15: 47n; C_0603_1608Metric
C16: 4.7u; C_0603_1608Metric
CR1: SMBJ5.0A-TR; MPN SMBJ5.0A-TR; Digi-Key_PN 497-3144-1-ND
D3: GREEN; LED_0603_1608Metric
D4: RED; LED_0603_1608Metric
J4, J10, J11: Conn_01x01; TestPoint_Pad_1.5x1.5mm
J8: UJC-HP-3-SMT-TR
L1, L2: 1 μ; SPM5020T-1R0M
R9, R11: 5.1k; R_0402_1005Metric; MPN RC0603FR-075K1L; Digi-Key_PN 311-5.10KHRCT-ND
R10: 1M; R_0402_1005Metric; MPN RC0603FR-071KL; Digi-Key_PN 311-1.00KHRCT-ND
R12: 150; R_0603_1608Metric; MPN RC0603FR-075K1L; Digi-Key_PN 311-5.10KHRCT-ND
R13: 510; R_0603_1608Metric; MPN RC0603FR-075K1L; Digi-Key_PN 311-5.10KHRCT-ND
R14, R15: 1k; R_0603_1608Metric; MPN RC0603FR-075K1L; Digi-Key_PN 311-5.10KHRCT-ND
R16, R17: 10k; R_0402_1005Metric; MPN RC0603FR-075K1L; Digi-Key_PN 311-5.10KHRCT-ND
S1: JS102011JAQN; SW_JS102011JAQN; PARTREV 29 June 16
U4: TPS61235PRWLR
U5: BQ25616RTWT; QFN50P400X400X80-25N

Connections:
/+5v: C10.1, C12.1, C13.1, J10.1, U4.6 (FB), U4.9 (VOUT); also elsewhere on the board
/PSUs/REGN: C16.1, R16.2, U5.22 (REGN)
/PSUs/SYS: C9.1, C18.1, D3.2 (A), D4.2 (A), L1.1, L2.2, S1.3, S1.3.1 (3), U4.3 (VIN), U5.15 (SYS), U5.16 (SYS)
/PSUs/VBUS: C11.1, CR1.1, J4.1, J8.2, J8.5, U5.1 (VAC), U5.9 (CE), U5.24 (VBUS)
GND: B1.1 (-), C9.2, C10.2, C11.2, C12.2, C13.2, C14.2, C16.2, C17.2, C18.2, CR1.2, J8.1, J8.6, J11.1, R9.2, R10.2, R11.2, R12.1, R13.1, R17.1, U4.1 (PGND), U4.4 (CC), U4.5 (AGND), U4.8 (INACT), U5.17 (GND), U5.18 (GND), U5.25 (ThermalPAD); also elsewhere on the board
unnamed: B1.2 (+), C17.1, U5.13 (BAT), U5.14 (BAT)
unnamed: C14.1, U5.23 (PMID)
unnamed: C15.1, L2.1, U5.19 (SW), U5.20 (SW)
unnamed: C15.2, U5.21 (BTST)
unnamed: D3.1 (K), R14.1
unnamed: D4.1 (K), R15.1
unnamed: J8.3, R9.1
unnamed: J8.4, R11.1
unnamed: L1.2, U4.2 (SW)
unnamed: R10.1, S1.1, S1.1.1 (1)
unnamed: R12.2, U5.8 (ILIM)
unnamed: R13.2, U5.10 (ICHG)
unnamed: R14.2, U5.5 (STAT)
unnamed: R15.2, U5.7 (PG)
unnamed: R16.1, R17.2, U5.11 (TS)
unnamed: S1.2, S1.2.1 (2), U4.7 (EN)

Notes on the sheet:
USB-C (Power Only)
Place as close to BQ2561 as possible
Short pads if not using battery and charging circuitry

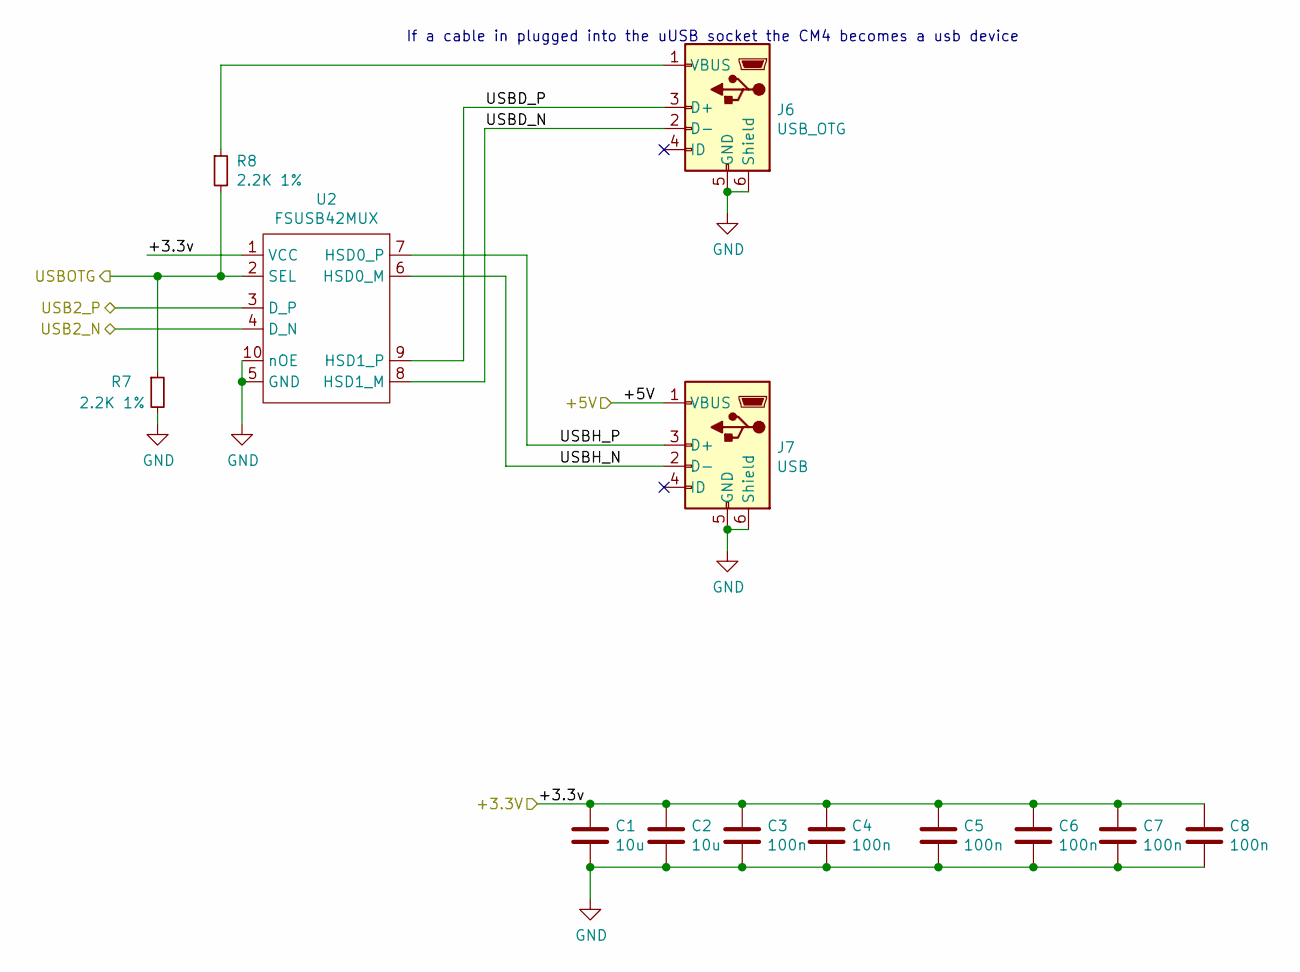
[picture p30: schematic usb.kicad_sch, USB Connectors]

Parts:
C1, C2: 10u; C_0805_2012Metric; Part Description 10uF 10% 10V Ceramic Capacitor X7R 0805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
C3, C4, C5, C6, C7, C8: 100n; C_0402_1005Metric; Part Description 0.1uF 10% 16V Ceramic Capacitor X7R 040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
J6: USB_OTG; USB_Micro-B_Molex-105017-0001; Part Description USB - micro B USB 2.0 Receptacle Connec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
J7: USB; USB_Micro-B_Molex-105017-0001; Part Description USB - micro B USB 2.0 Receptacle Connec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
R7, R8: 2.2K 1%; R_0402_1005Metric; Part Description Resistor 2.2K M1005 1% 63mW
U2: FSUSB42MUX; MSOP-10_3x3mm_P0.5mm; Part Description USB Switch IC 1 Channel 10-MSOP

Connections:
/+3.3v: C1.1, C2.1, C3.1, C4.1, C5.1, C6.1, C7.1, C8.1, U2.1 (VCC); also elsewhere on the board
/+5v: J7.1 (VBUS); also elsewhere on the board
/CM4 High Speed/USB2_N: U2.4 (D_N); also elsewhere on the board
/CM4 High Speed/USB2_P: U2.3 (D_P); also elsewhere on the board
/CM4 High Speed/USBOTG: R7.1, R8.2, U2.2 (SEL); also elsewhere on the board
/USB/USBD_N: J6.2 (D-), U2.8 (HSD1_M)
/USB/USBD_P: J6.3 (D+), U2.9 (HSD1_P)
/USB/USBH_N: J7.2 (D-), U2.6 (HSD0_M)
/USB/USBH_P: J7.3 (D+), U2.7 (HSD0_P)
GND: C1.2, C2.2, C3.2, C4.2, C5.2, C6.2, C7.2, C8.2, J6.5 (GND), J6.6 (Shield), J7.5 (GND), J7.6 (Shield), R7.2, U2.5 (GND), U2.10 (nOE); also elsewhere on the board
unnamed: J6.1 (VBUS), R8.1

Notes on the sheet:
If a cable in plugged into the uUSB socket the CM4 becomes a usb device

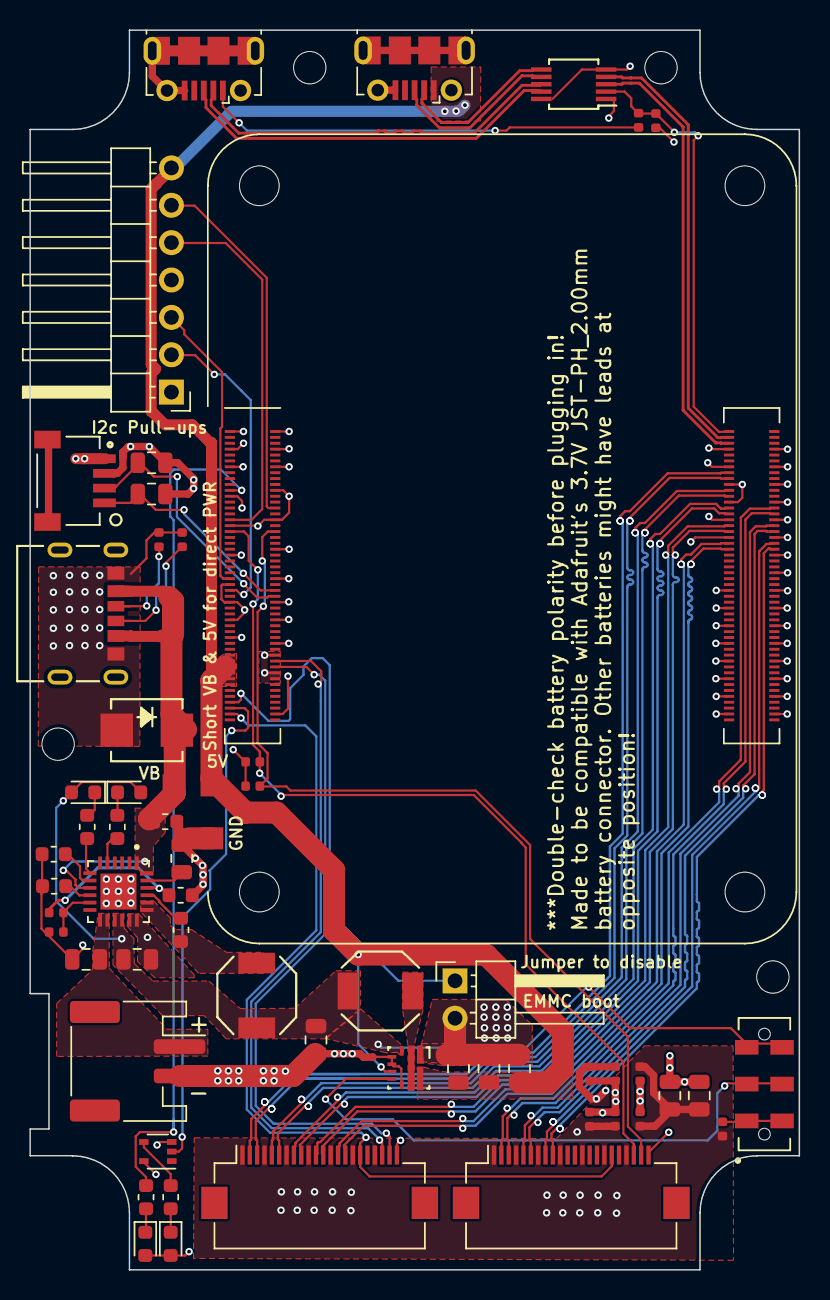
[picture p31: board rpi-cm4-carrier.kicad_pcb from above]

Board: 4 copper layers, 52.3 x 84.2 mm, 60 parts (0 on the bottom side), 63 nets.

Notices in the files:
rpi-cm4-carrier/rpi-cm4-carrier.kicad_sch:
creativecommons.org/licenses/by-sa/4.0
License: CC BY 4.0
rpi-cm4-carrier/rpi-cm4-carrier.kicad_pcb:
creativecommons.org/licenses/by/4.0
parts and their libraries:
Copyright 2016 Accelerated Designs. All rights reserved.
